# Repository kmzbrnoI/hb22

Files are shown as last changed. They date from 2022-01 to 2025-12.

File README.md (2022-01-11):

HB22
====

DCC signal booster

## Features

* Input voltage: track+1V – 35 V **DC**
* Output voltage: 14–25 V DCC
* Maximum output current: 3 A
* Adjustable output voltage
* Stepdown for stabilization (energy-effective)
* No big cooler needed
* Analog current limitation to 3 A
* DCC skew rate limitation
* RailCom support
* Possibility to connect expansion module for integration with railroad-control system
* Current sensing, voltage sensing, temperature sensing
* Short-circuit detection, (configurable) automatic restore after short-circuit

## Available expansion modules

- [MTBbus expansion module](exp-mtb)

## Principles

Main MCU does all safety-critical operations:

* Detection of short-circuit
* Railcom pause insertion

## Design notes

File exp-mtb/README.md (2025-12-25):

HB22 MTBbus expansion module
============================

The module allows communication with HB22 booster over
[MTBbus](https://mtb.kmz-brno.cz/).

## Module inputs

1. `BAI` Booster active [bool]
  - `BAO` && `BO` && `DCCI`
2. `BO` Booster ok [bool]
  - Communication with HB22 main MCU ok && HB22 main MCU reports status ok
3. `DCCI` Valid DCC on input [bool]
4. `SC` Shortcut [bool]

### Analog inputs

1. `OV` Output voltage
2. `OC` Output current
3. `TVR` Voltage regulator temperature
4. `TCR` Current limiter temperature

## Module outputs

1. `BAO` Booster active [bool]
2. `SCR` Shortcut renewal active [bool]

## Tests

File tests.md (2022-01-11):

Testovací scénáře zesilovače HB22
=================================

* Vysoké napětí na vstupu
* Nízké napětí na vstupu
* Opačné napětí na vstupu (standardní i vysoké)
* Standardní napětí přivedeno na výstup místo na vstup
* Standardní napětí přivedeno na vstup i na výstup
* Vysoké napětí přivedeno na výstup (vstup aktivní i neaktivní)
* Prohozené zapojení vstupu a výstupu
* Propojený vstup a výstup, přivedeno napětí
* Osazený, ale nenapájený expandér
* Spojení výstupů dvou HB22
  - Galvanicky spojené zesilovače
  - Galvanicky rozpojené zesilovače
* Spojení výstupů dvou HB22 překřížené
  - Galvanicky spojené zesilovače
  - Galvanicky rozpojené zesilovače
* Spojení výstupů HB22 a jiného zesilovače
  - Galvanicky spojené zesilovače
  - Galvanicky rozpojené zesilovače
* Spojení výstupů HB22 a jiného zesilovače překřížené
  - Galvanicky spojené zesilovače
  - Galvanicky rozpojené zesilovače
* Elektrostatický impuls na IO konektorech

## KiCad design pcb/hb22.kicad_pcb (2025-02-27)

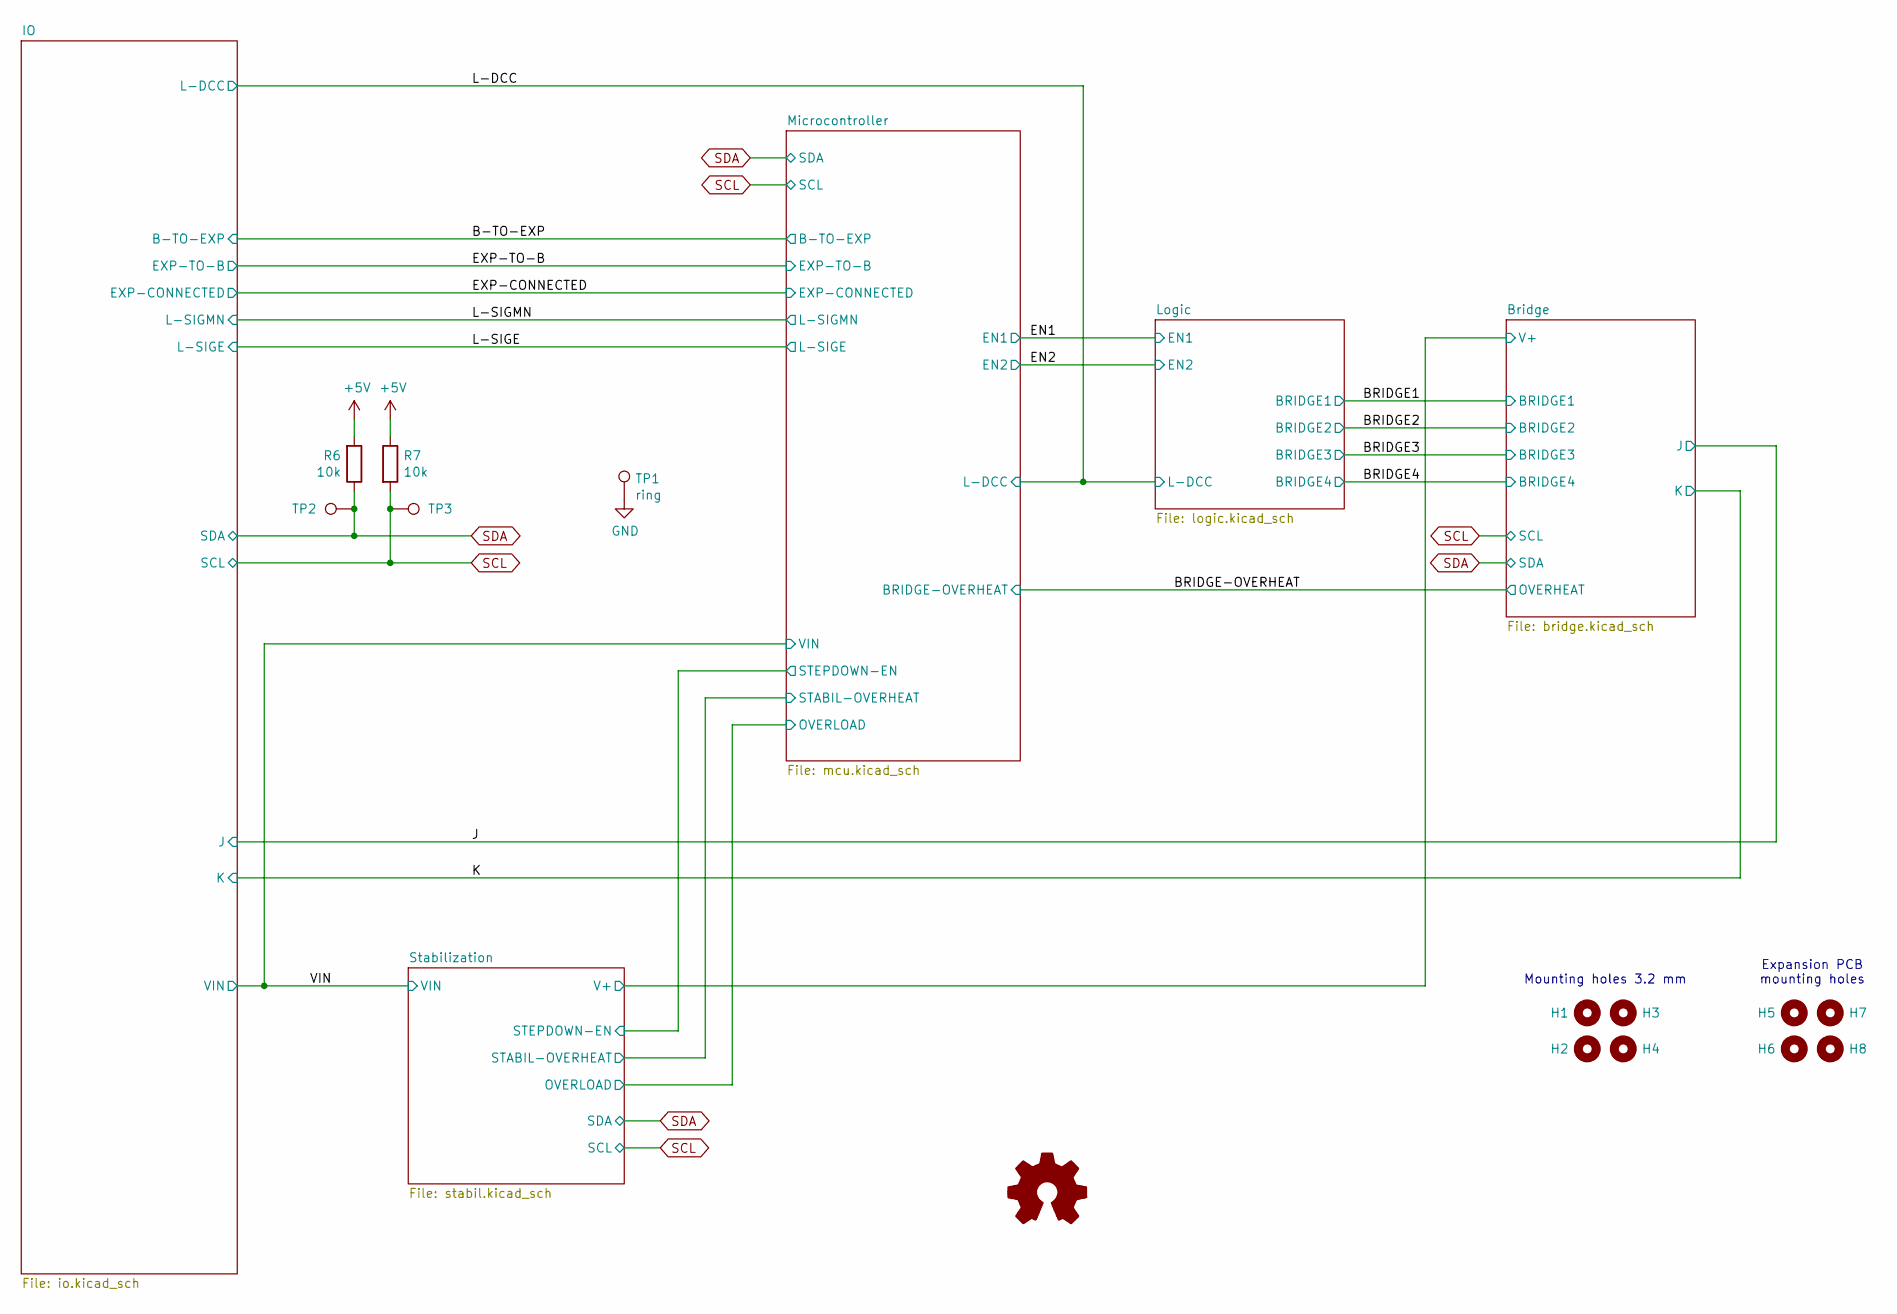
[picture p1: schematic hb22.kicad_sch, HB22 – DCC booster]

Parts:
H1, H2, H3, H4, H5, H6, H7, H8: MountingHole_3.2mm_M3_Pad
R6, R7: 10k; R_0805_2012Metric; LCSC C17414
TP1: ring; TestPoint_Loop_D1.80mm_Drill1.0mm_Beaded
TP2, TP3: TestPoint; TestPoint_Pad_D1.0mm

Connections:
+5V: R6.2, R7.1; also elsewhere on the board
GND: TP1.1; also elsewhere on the board
SCL: R7.2, TP3.1; also elsewhere on the board
SDA: R6.1, TP2.1; also elsewhere on the board

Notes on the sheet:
Mounting holes 3.2 mm
Expansion PCB mounting holes

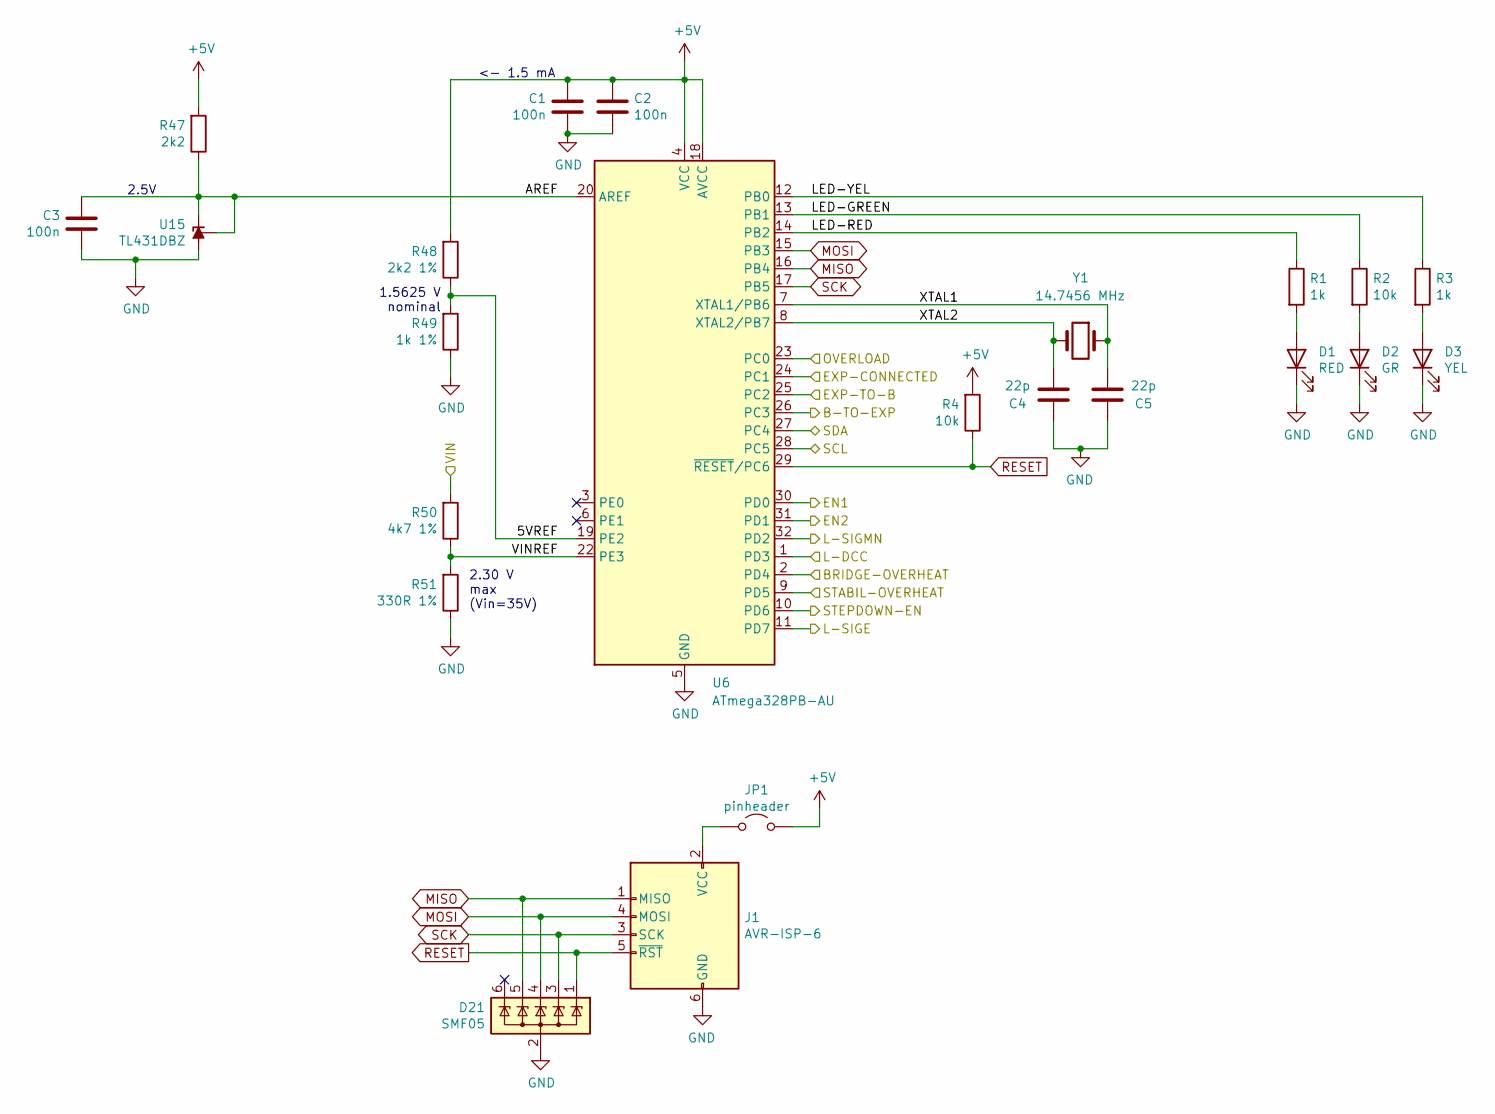
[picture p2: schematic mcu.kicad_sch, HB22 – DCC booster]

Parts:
C1, C2, C3: 100n; C_0805_2012Metric; LCSC C49678
C4, C5: 22p; C_0805_2012Metric; LCSC C1804
D1: RED; LED_0805_2012Metric; LCSC C84256
D2: GR; LED_0805_2012Metric; LCSC C2297
D3: YEL; LED_0805_2012Metric; LCSC C2293
D21: SMF05; SOT-363_SC-70-6
J1: AVR-ISP-6; PinHeader_2x03_P2.54mm_Vertical
JP1: pinheader; PinHeader_1x02_P2.54mm_Vertical
R1, R3: 1k; R_0805_2012Metric; LCSC C17513
R2: 10k; R_0805_2012Metric; LCSC C17513
R4: 10k; R_0805_2012Metric; LCSC C17414
R47: 2k2; R_0805_2012Metric
R48: 2k2 1%; R_0805_2012Metric
R49: 1k 1%; R_0805_2012Metric
R50: 4k7 1%; R_0805_2012Metric
R51: 330R 1%; R_0805_2012Metric
U6: ATmega328PB-AU; TQFP-32_7x7mm_P0.8mm
U15: TL431DBZ; SOT-23; LCSC C3113
Y1: 14.7456 MHz; Crystal_SMD_HC49-SD; LCSC C240976

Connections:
+5V: C1.2, C2.1, JP1.1 (A), R4.2, R47.2, R48.2, U6.4 (VCC), U6.18 (AVCC); also elsewhere on the board
/B-TO-EXP: U6.26 (PC3); also elsewhere on the board
/BRIDGE-OVERHEAT: U6.2 (PD4); also elsewhere on the board
/EN1: U6.30 (PD0); also elsewhere on the board
/EN2: U6.31 (PD1); also elsewhere on the board
/EXP-CONNECTED: U6.24 (PC1); also elsewhere on the board
/EXP-TO-B: U6.25 (PC2); also elsewhere on the board
/L-DCC: U6.1 (PD3); also elsewhere on the board
/L-SIGE: U6.11 (PD7); also elsewhere on the board
/L-SIGMN: U6.32 (PD2); also elsewhere on the board
/Microcontroller/5VREF: R48.1, R49.2, U6.19 (PE2)
/Microcontroller/AREF: C3.2, R47.1, U6.20 (AREF), U15.1 (K), U15.2 (REF)
/Microcontroller/LED-GREEN: R2.1, U6.13 (PB1)
/Microcontroller/LED-RED: R1.1, U6.14 (PB2)
/Microcontroller/LED-YEL: R3.1, U6.12 (PB0)
/Microcontroller/OVERLOAD: U6.23 (PC0); also elsewhere on the board
/Microcontroller/STABIL-OVERHEAT: U6.9 (PD5); also elsewhere on the board
/Microcontroller/STEPDOWN-EN: U6.10 (PD6); also elsewhere on the board
/Microcontroller/VINREF: R50.1, R51.2, U6.22 (PE3)
/Microcontroller/XTAL1: C5.1, U6.7 (XTAL1/PB6), Y1.1
/Microcontroller/XTAL2: C4.2, U6.8 (XTAL2/PB7), Y1.2
/VIN: R50.2; also elsewhere on the board
GND: C1.1, C2.2, C3.1, C4.1, C5.2, D1.1 (K), D2.1 (K), D3.1 (K), D21.2 (A), J1.6 (GND), R49.1, R51.1, U6.5 (GND), U6.21 (GND), U15.3 (A); also elsewhere on the board
MISO: D21.5 (K), J1.1 (MISO), U6.16 (PB4)
MOSI: D21.4 (K), J1.4 (MOSI), U6.15 (PB3)
unnamed: D1.2 (A), R1.2
unnamed: D2.2 (A), R2.2
unnamed: D3.2 (A), R3.2
unnamed: J1.2 (VCC), JP1.2 (B)
RESET: D21.1 (K), J1.5 (~RST), R4.1, U6.29 (~RESET/PC6)
SCK: D21.3 (K), J1.3 (SCK), U6.17 (PB5)
SCL: U6.28 (PC5); also elsewhere on the board
SDA: U6.27 (PC4); also elsewhere on the board

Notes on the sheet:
1.5625 V nominal
<- 1.5 mA
2.5V
2.30 V max (Vin=35V)

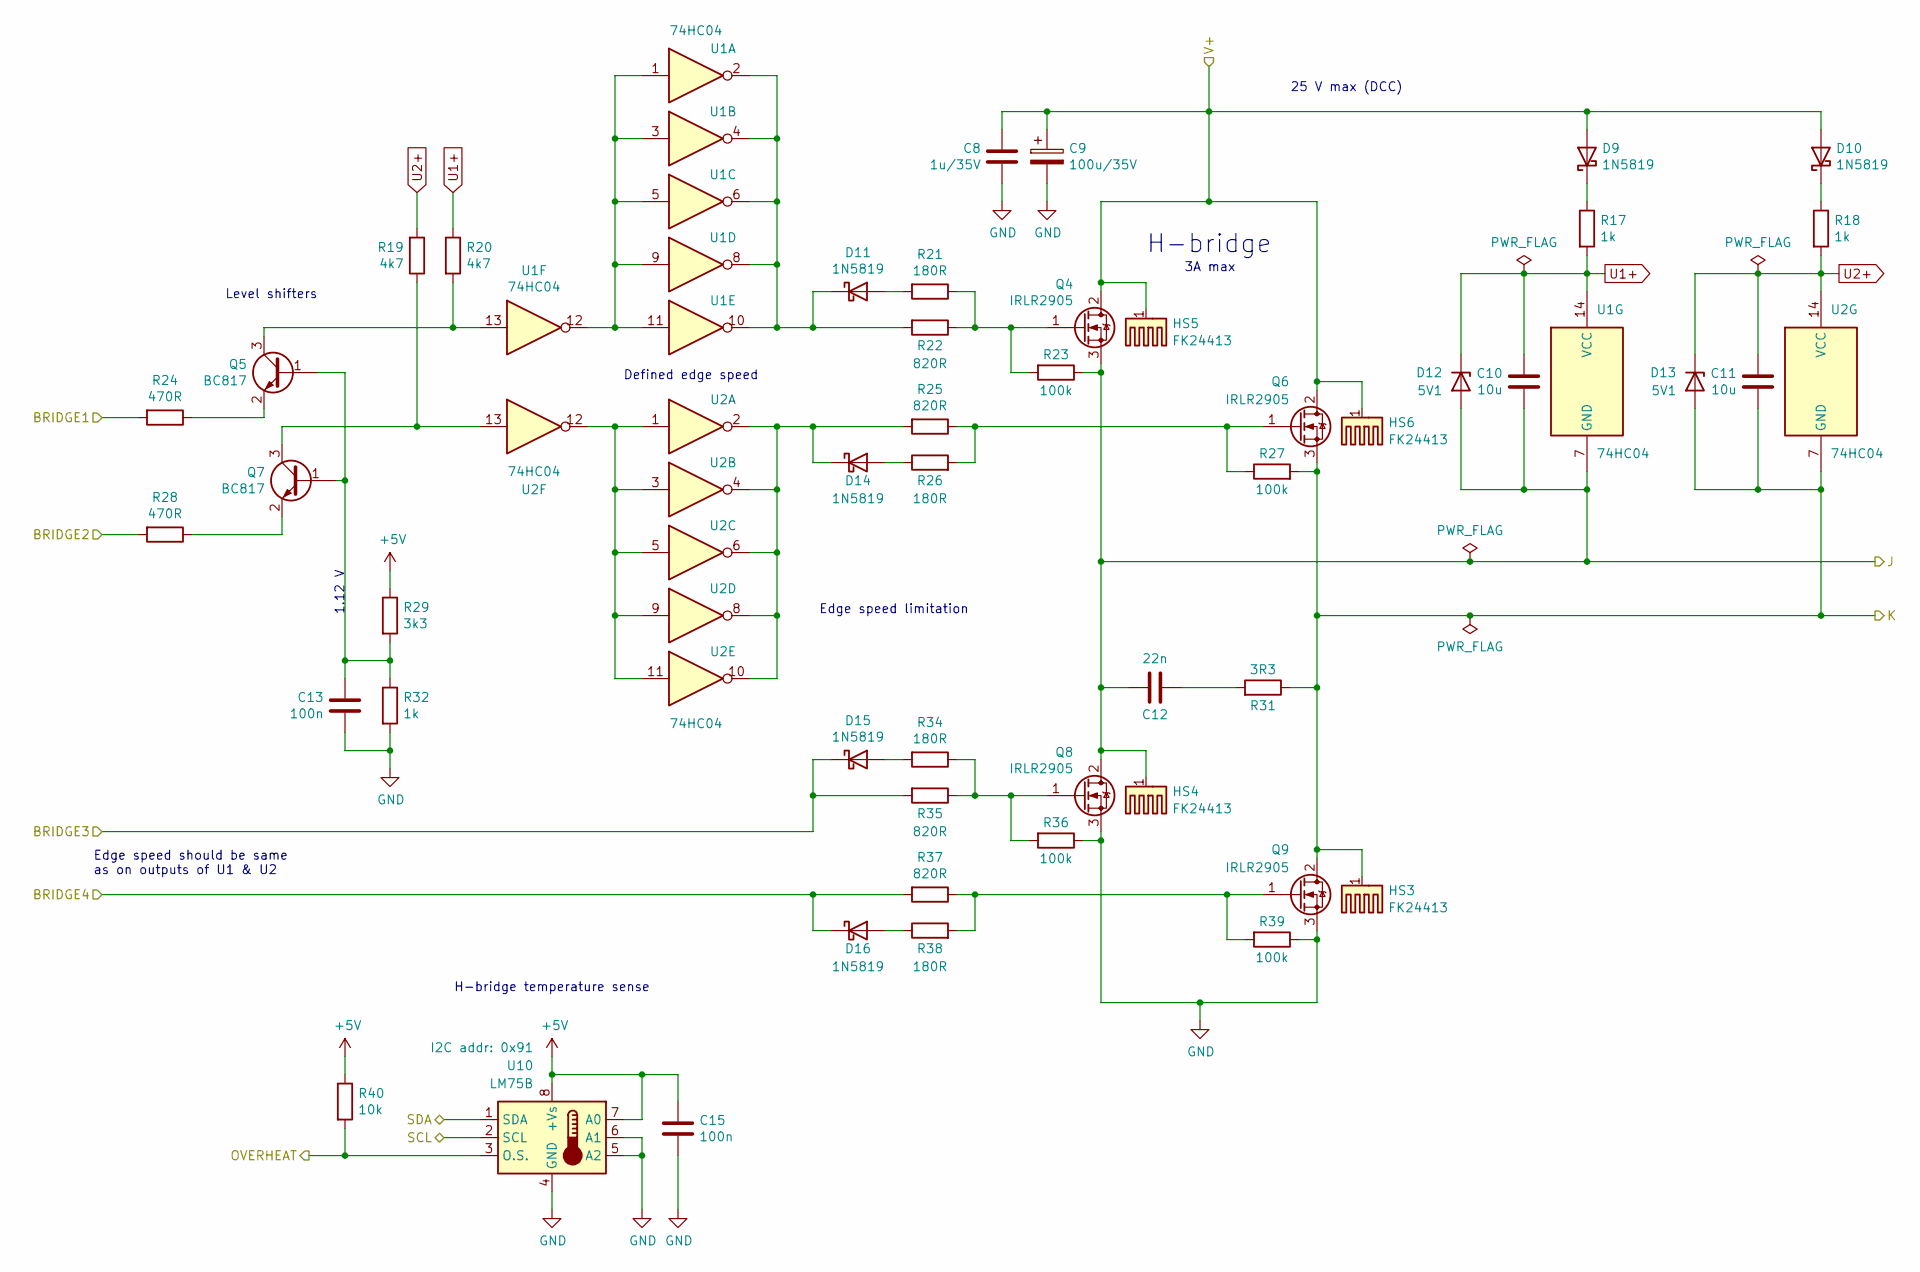
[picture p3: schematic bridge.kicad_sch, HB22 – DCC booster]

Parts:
C8: 1u/35V; C_0805_2012Metric
C9: 100u/35V; CP_Radial_D6.3mm_P2.50mm
C10, C11: 10u; C_0805_2012Metric
C12: 22n; C_0805_2012Metric
C13, C15: 100n; C_0805_2012Metric
D9, D10, D11, D14, D15, D16: 1N5819; D_SOD-123
D12, D13: 5V1; SOT-23
HS3, HS4, HS5, HS6: FK24413; Heatsink_Fischer_FK24413DPAK_23x13mm
Q4, Q6, Q8, Q9: IRLR2905; TO-252-2
Q5, Q7: BC817; SOT-23
R17, R18: 1k; R_2512_6332Metric
R19, R20: 4k7; R_0805_2012Metric
R21, R26, R34, R38: 180R; R_0805_2012Metric
R22, R25, R35, R37: 820R; R_0805_2012Metric
R23, R27, R36, R39: 100k; R_0805_2012Metric
R24, R28: 470R; R_0805_2012Metric
R29: 3k3; R_0805_2012Metric
R31: 3R3; R_0805_2012Metric
R32: 1k; R_0805_2012Metric
R40: 10k; R_0805_2012Metric
U1, U2: 74HC04; DIP-14_W8.89mm_SMDSocket_LongPads
U10: LM75B; SOIC-8_3.9x4.9mm_P1.27mm

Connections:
+5V: C15.1, R29.1, R40.1, U10.7 (A0), U10.8 (+Vs); also elsewhere on the board
/BRIDGE1: R24.2; also elsewhere on the board
/BRIDGE2: R28.2; also elsewhere on the board
/BRIDGE3: D15.1 (K), R35.2; also elsewhere on the board
/BRIDGE4: D16.1 (K), R37.2; also elsewhere on the board
/BRIDGE-OVERHEAT: R40.2, U10.3 (O.S.); also elsewhere on the board
/Bridge/V+: C8.2, C9.1, D9.2 (A), D10.2 (A), HS5.1, HS6.1, Q4.2 (D), Q6.2 (D); also elsewhere on the board
/J: C10.1, C12.2, D12.1 (A), HS4.1, Q4.3 (S), Q8.2 (D), R23.1, U1.7 (GND); also elsewhere on the board
/K: C11.1, D13.1 (A), HS3.1, Q6.3 (S), Q9.2 (D), R27.2, R31.1, U2.7 (GND); also elsewhere on the board
GND: C8.1, C9.2, C13.1, C15.2, Q8.3 (S), Q9.3 (S), R32.2, R36.1, R39.1, U10.4 (GND), U10.5 (A2), U10.6 (A1); also elsewhere on the board
unnamed: C12.1, R31.2
unnamed: D9.1 (K), R17.1
unnamed: D10.1 (K), R18.1
unnamed: D11.2 (A), R21.2
unnamed: D11.1 (K), R22.2, U1.2, U1.4, U1.6, U1.8, U1.10
unnamed: D14.2 (A), R26.1
unnamed: D14.1 (K), R25.2, U2.2, U2.4, U2.6, U2.8, U2.10
unnamed: D15.2 (A), R34.2
unnamed: D16.2 (A), R38.1
unnamed: Q4.1 (G), R21.1, R22.1, R23.2
unnamed: C13.2, Q5.1 (B), Q7.1 (B), R29.2, R32.1
unnamed: Q5.3 (C), R20.2, U1.13
unnamed: Q5.2 (E), R24.1
unnamed: Q6.1 (G), R25.1, R26.2, R27.1
unnamed: Q7.3 (C), R19.1, U2.13
unnamed: Q7.2 (E), R28.1
unnamed: Q8.1 (G), R34.1, R35.1, R36.2
unnamed: Q9.1 (G), R37.1, R38.2, R39.2
unnamed: U1.1, U1.3, U1.5, U1.9, U1.11, U1.12
unnamed: U2.1, U2.3, U2.5, U2.9, U2.11, U2.12
SCL: U10.2 (SCL); also elsewhere on the board
SDA: U10.1 (SDA); also elsewhere on the board
U1+: C10.2, D12.3 (K), R17.2, R20.1, U1.14 (VCC)
U2+: C11.2, D13.3 (K), R18.2, R19.2, U2.14 (VCC)

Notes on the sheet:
25 V max (DCC)
3A max
1.12 V
H-bridge
Defined edge speed
Edge speed should be same as on outputs of U1 & U2
Edge speed limitation
H-bridge temperature sense
Level shifters

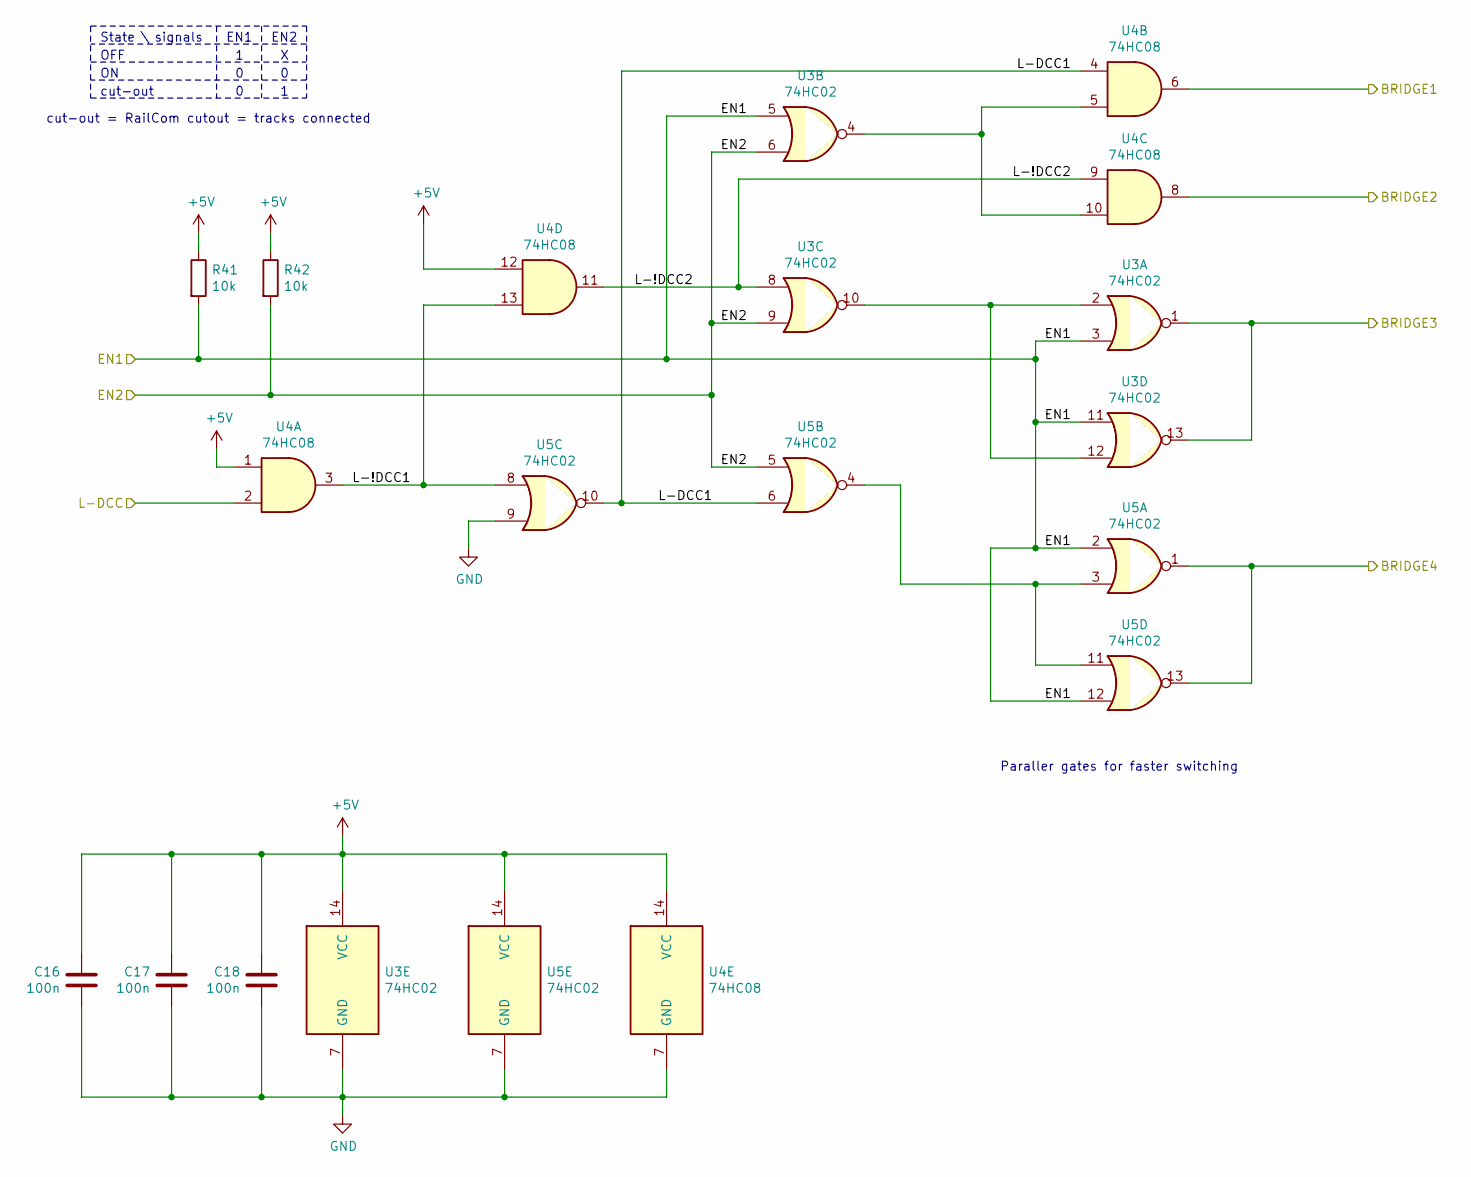
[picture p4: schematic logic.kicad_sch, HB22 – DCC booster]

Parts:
C16, C17, C18: 100n; C_0805_2012Metric
R41, R42: 10k; R_0805_2012Metric
U3, U5: 74HC02; DIP-14_W8.89mm_SMDSocket_LongPads
U4: 74HC08; DIP-14_W8.89mm_SMDSocket_LongPads

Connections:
+5V: C16.2, C17.2, C18.2, R41.1, R42.1, U3.14 (VCC), U4.1, U4.12, U4.14 (VCC), U5.14 (VCC); also elsewhere on the board
/BRIDGE1: U4.6; also elsewhere on the board
/BRIDGE2: U4.8; also elsewhere on the board
/BRIDGE3: U3.1, U3.13; also elsewhere on the board
/BRIDGE4: U5.1, U5.13; also elsewhere on the board
/EN1: R41.2, U3.3, U3.5, U3.11, U5.2, U5.12; also elsewhere on the board
/EN2: R42.2, U3.6, U3.9, U5.5; also elsewhere on the board
/L-DCC: U4.2; also elsewhere on the board
/Logic/L-!DCC1: U4.3, U4.13, U5.8
/Logic/L-!DCC2: U3.8, U4.9, U4.11
/Logic/L-DCC1: U4.4, U5.6, U5.10
GND: C16.1, C17.1, C18.1, U3.7 (GND), U4.7 (GND), U5.7 (GND), U5.9; also elsewhere on the board
unnamed: U3.4, U4.5, U4.10
unnamed: U3.2, U3.10, U3.12
unnamed: U5.3, U5.4, U5.11

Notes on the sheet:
EN2
State \ signals
OFF
Paraller gates for faster switching
cut-out = RailCom cutout = tracks connected
cut-out
EN1

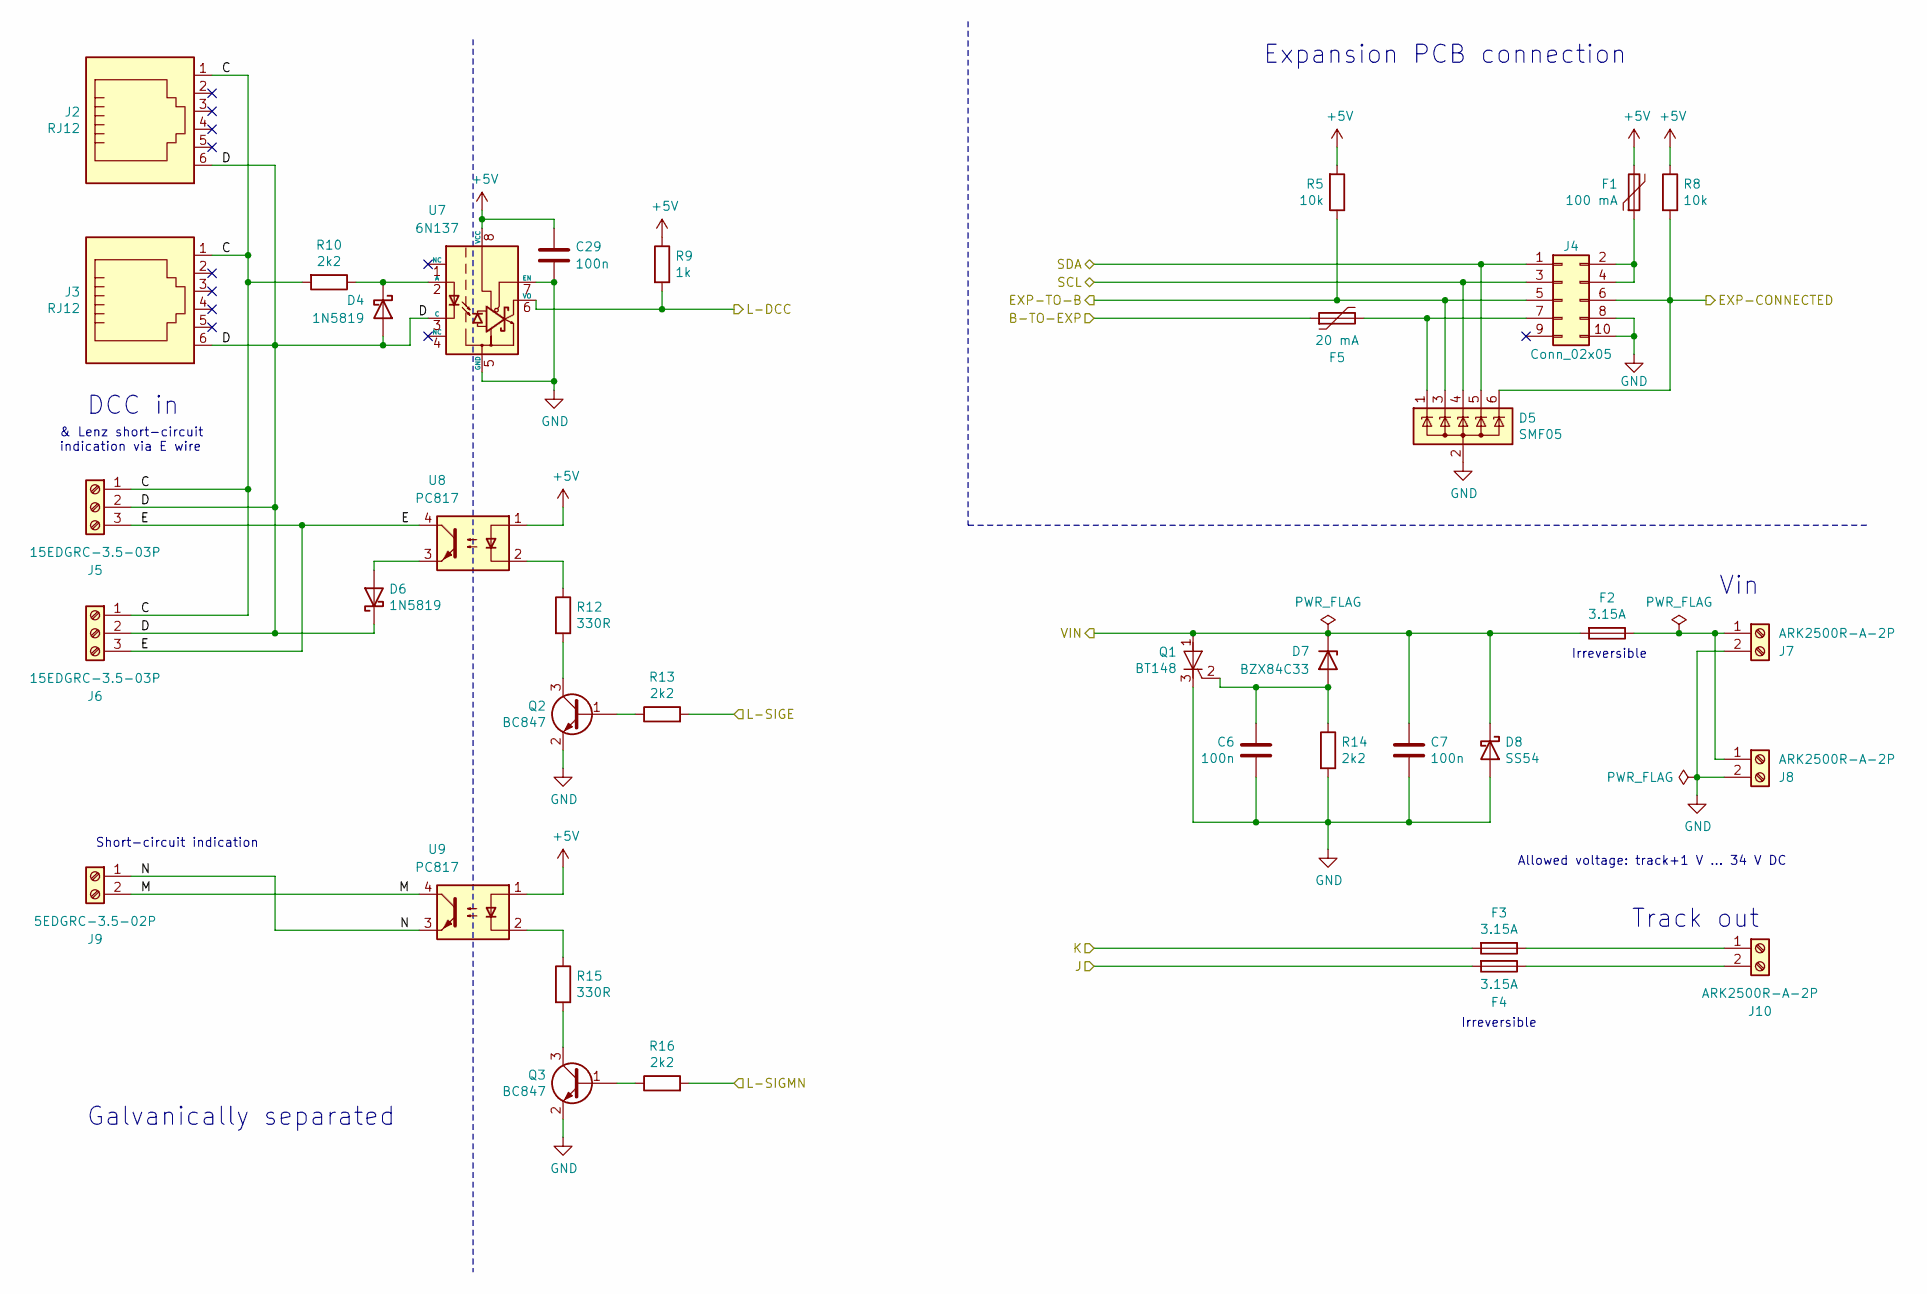
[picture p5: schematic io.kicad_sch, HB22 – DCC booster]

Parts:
C6, C7, C29: 100n; C_0805_2012Metric
D4, D6: 1N5819; D_SOD-123
D5: SMF05; SOT-363_SC-70-6
D7: BZX84C33; SOT-23
D8: SS54; D_SMA
F1: 100 mA; Fuse_1206_3216Metric
F2, F3, F4: 3.15A; Fuseholder_Cylinder-5x20mm_Stelvio-Kontek_PTF78_Horizontal_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
F5: 20 mA; Fuse_1206_3216Metric
J2, J3: RJ12; RJ25_Wayconn_MJEA-660X1_Horizontal
J4: Conn_02x05; PinSocket_2x05_P2.54mm_Vertical
J5, J6: 15EDGRC-3.5-03P; PhoenixContact_MC_1,5_3-G-3.5_1x03_P3.50mm_Horizontal
J7, J8, J10: ARK2500R-A-2P; PhoenixContact_MSTBA_2,5_2-G_1x02_P5.00mm_Horizontal
J9: 5EDGRC-3.5-02P; PhoenixContact_MC_1,5_2-G-3.5_1x02_P3.50mm_Horizontal
Q1: BT148; SOT-223
Q2, Q3: BC847; SOT-23
R5: 10k; R_0805_2012Metric; LCSC C17414
R8: 10k; R_0805_2012Metric
R9: 1k; R_0805_2012Metric
R10, R13, R14, R16: 2k2; R_0805_2012Metric
R12, R15: 330R; R_0805_2012Metric
U7: 6N137; DIP-8_W8.89mm_SMDSocket_LongPads
U8, U9: PC817; DIP-4_W8.89mm_SMDSocket_LongPads

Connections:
+5V: C29.1, F1.2, R5.2, R8.1, R9.1, U7.8 (VCC), U8.1, U9.1; also elsewhere on the board
/B-TO-EXP: F5.1; also elsewhere on the board
/EXP-CONNECTED: D5.6 (K), J4.6, R8.2; also elsewhere on the board
/EXP-TO-B: D5.3 (K), J4.5, R5.1; also elsewhere on the board
/IO/C: J2.1, J3.1, J5.1, J6.1, R10.2
/IO/D: D4.2 (A), D6.1 (K), J2.6, J3.6, J5.2, J6.2, U7.3 (C)
/IO/E: J5.3, J6.3, U8.4
/IO/M: J9.2, U9.4
/IO/N: J9.1, U9.3
/J: F4.2; also elsewhere on the board
/K: F3.2; also elsewhere on the board
/L-DCC: R9.2, U7.6 (VO); also elsewhere on the board
/L-SIGE: R13.2; also elsewhere on the board
/L-SIGMN: R16.2; also elsewhere on the board
/VIN: C7.1, D7.3 (K), D8.1 (K), F2.2, Q1.1 (A); also elsewhere on the board
GND: C6.1, C7.2, C29.2, D5.2 (A), D8.2 (A), J4.8, J4.10, J7.2, J8.2, Q1.3 (K), Q2.2 (E), Q3.2 (E), R14.2, U7.5 (GND), U7.7 (EN); also elsewhere on the board
unnamed: D4.1 (K), R10.1, U7.2 (A)
unnamed: D6.2 (A), U8.3
unnamed: C6.2, D7.1 (A), Q1.2 (G), R14.1
unnamed: F1.1, J4.2, J4.4
unnamed: D5.1 (K), F5.2, J4.7
unnamed: F2.1, J7.1, J8.1
unnamed: F3.1, J10.1
unnamed: F4.1, J10.2
unnamed: Q2.1 (B), R13.1
unnamed: Q2.3 (C), R12.2
unnamed: Q3.1 (B), R16.1
unnamed: Q3.3 (C), R15.2
unnamed: R12.1, U8.2
unnamed: R15.1, U9.2
SCL: D5.4 (K), J4.3; also elsewhere on the board
SDA: D5.5 (K), J4.1; also elsewhere on the board

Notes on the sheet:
Allowed voltage: track+1 V ... 34 V DC
Irreversible
Vin
& Lenz short-circuit indication via E wire
Galvanically separated
Track out
Expansion PCB connection
Short-circuit indication
DCC in

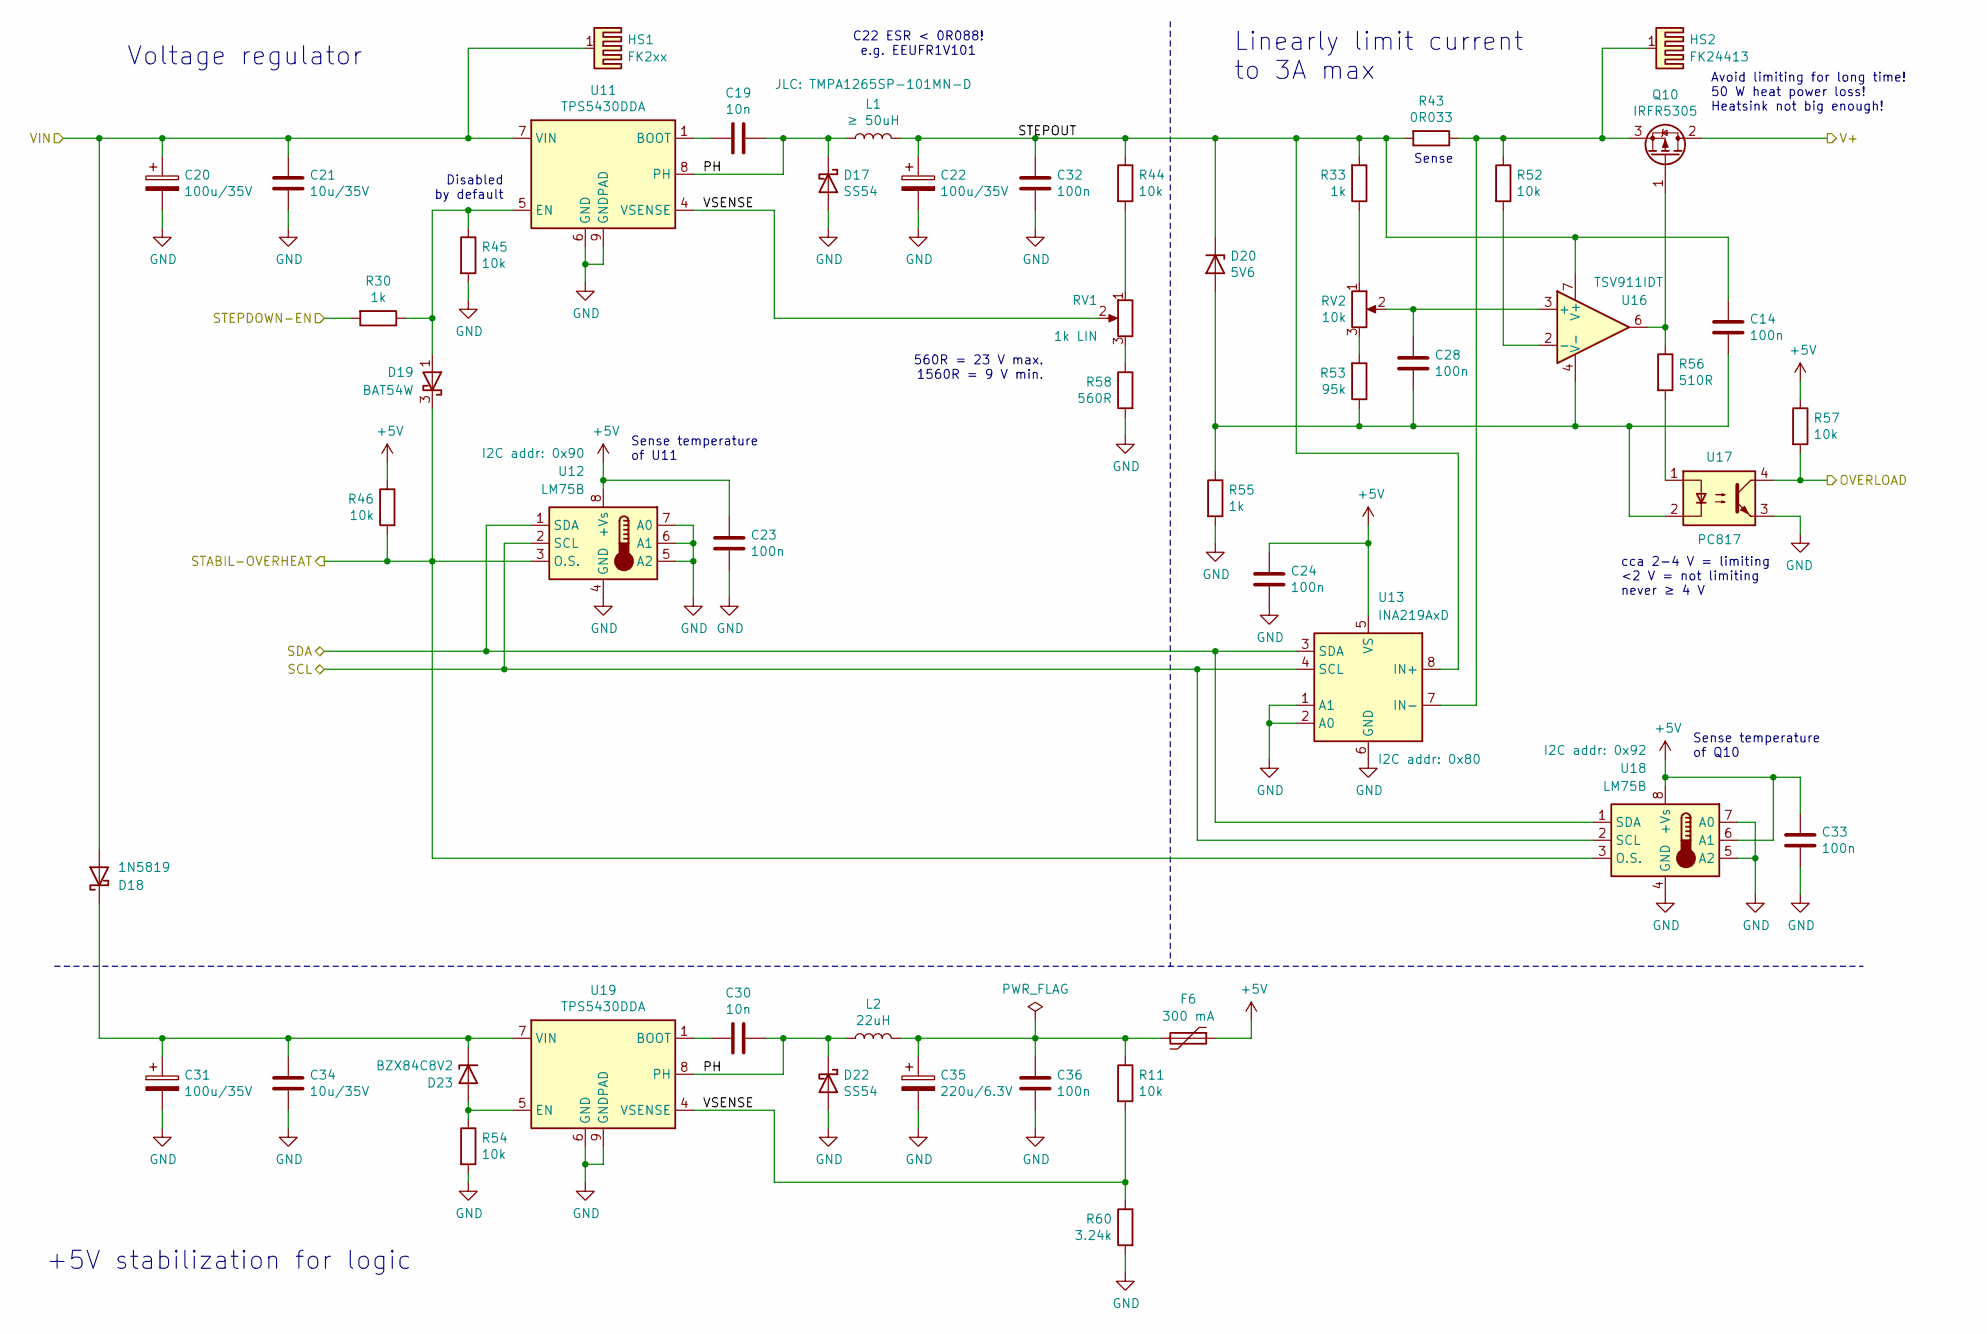
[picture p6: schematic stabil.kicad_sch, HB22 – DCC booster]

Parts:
C14, C23, C24, C28, C32, C33, C36: 100n; C_0805_2012Metric
C19, C30: 10n; C_0805_2012Metric
C20, C31: 100u/35V; CP_Radial_D6.3mm_P2.50mm
C21, C34: 10u/35V; C_0805_2012Metric
C22: 100u/35V; CP_Radial_D8.0mm_P3.50mm
C35: 220u/6.3V; CP_Radial_D8.0mm_P3.50mm
D17, D22: SS54; D_SMA
D18: 1N5819; D_SOD-123
D19: BAT54W; SOT-323_SC-70
D20: 5V6; SOT-23
D23: BZX84C8V2; SOT-23
F6: 300 mA; Fuse_2920_7451Metric
HS1: FK2xx; Heatsink_Fischer_FK24413DPAK_23x13mm
HS2: FK24413; Heatsink_Fischer_FK24413DPAK_23x13mm
L1: ≥ 50uH; L_TaiTech_TMPC1265_13.5x12.5mm; JLC TMPA1265SP-101MN-D
L2: 22uH; L_Changjiang_FNR4020S
Q10: IRFR5305; TO-252-2
R11, R44, R45, R46, R52, R54, R57: 10k; R_0805_2012Metric
R30, R33: 1k; R_0805_2012Metric
R43: 0R033; R_2512_6332Metric
R53: 95k; R_0805_2012Metric
R55: 1k; R_2512_6332Metric
R56: 510R; R_0805_2012Metric
R58: 560R; R_0805_2012Metric
R60: 3.24k; R_0805_2012Metric
RV1: 1k LIN; Potentiometer_Piher_PT-6-V_Vertical
RV2: 10k; Potentiometer_Piher_PT-6-V_Vertical
U11, U19: TPS5430DDA; TI_SO-PowerPAD-8_ThermalVias
U12, U18: LM75B; SOIC-8_3.9x4.9mm_P1.27mm
U13: INA219AxD; SOIC-8_3.9x4.9mm_P1.27mm
U16: TSV911IDT; SOIC-8_3.9x4.9mm_P1.27mm
U17: PC817; DIP-4_W8.89mm_SMDSocket_LongPads

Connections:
+5V: C23.1, C24.1, C33.1, F6.1, R46.1, R57.1, U12.8 (+Vs), U13.5 (VS), U18.6 (A1), U18.8 (+Vs); also elsewhere on the board
/Bridge/V+: Q10.2 (D); also elsewhere on the board
/Microcontroller/OVERLOAD: R57.2, U17.4; also elsewhere on the board
/Microcontroller/STABIL-OVERHEAT: D19.3 (K), R46.2, U12.3 (O.S.), U18.3 (O.S.); also elsewhere on the board
/Microcontroller/STEPDOWN-EN: R30.2; also elsewhere on the board
/Stabilization/PH: C19.1, C30.1, D17.1 (K), D22.1 (K), L1.1, L2.1, U11.8 (PH), U19.8 (PH)
/Stabilization/STEPOUT: C14.1, C22.1, C32.1, D20.3 (K), L1.2, R33.2, R43.2, R44.1, U13.8 (IN+), U16.7 (V+)
/Stabilization/VSENSE: R11.2, R60.1, RV1.2, U11.4 (VSENSE), U19.4 (VSENSE)
/VIN: C20.1, C21.1, D18.2 (A), HS1.1, U11.7 (VIN); also elsewhere on the board
GND: C20.2, C21.2, C22.2, C23.2, C24.2, C31.2, C32.2, C33.2, C34.2, C35.2, C36.2, D17.2 (A), D22.2 (A), R45.2, R54.2, R55.2, R58.2, R60.2, U11.6 (GND), U11.9 (GNDPAD), U12.4 (GND), U12.5 (A2), U12.6 (A1), U12.7 (A0), U13.1 (A1), U13.2 (A0), U13.6 (GND), U17.3, U18.4 (GND), U18.5 (A2), U18.7 (A0), U19.6 (GND), U19.9 (GNDPAD); also elsewhere on the board
unnamed: C35.1, C36.1, F6.2, L2.2, R11.1
unnamed: C31.1, C34.1, D18.1 (K), D23.3 (K), U19.7 (VIN)
unnamed: D19.1 (A), R30.1, R45.1, U11.5 (EN)
unnamed: C14.2, C28.2, D20.1 (A), R53.1, R55.1, U16.4 (V-), U17.2
unnamed: D23.1 (A), R54.1, U19.5 (EN)
unnamed: Q10.1 (G), R56.1, U16.6
unnamed: HS2.1, Q10.3 (S), R43.1, R52.1, U13.7 (IN-)
unnamed: R33.1, RV2.1
unnamed: R44.2, RV1.1
unnamed: R53.2, RV2.3
unnamed: R56.2, U17.1
unnamed: R58.1, RV1.3
unnamed: C19.2, U11.1 (BOOT)
unnamed: C28.1, RV2.2, U16.3 (+)
unnamed: R52.2, U16.2 (-)
unnamed: C30.2, U19.1 (BOOT)
SCL: U12.2 (SCL), U13.4 (SCL), U18.2 (SCL); also elsewhere on the board
SDA: U12.1 (SDA), U13.3 (SDA), U18.1 (SDA); also elsewhere on the board

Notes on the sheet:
Avoid limiting for long time! 50 W heat power loss! Heatsink not big enough!
560R = 23 V max. 1560R = 9 V min.
C22 ESR < 0R088! e.g. EEUFR1V101
Sense temperature of U11
Voltage regulator
cca 2-4 V = limiting <2 V = not limiting never ≥ 4 V
Disabled by default
+5V stabilization for logic
Sense
Sense temperature of Q10
Linearly limit current to 3A max

Board: 4 copper layers, 182 parts (0 on the bottom side), 106 nets, no tracks yet.

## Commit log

2021-12-28 Add empty KiCad project.
    [hb22.kicad_pcb, hb22.sch]
2021-12-28 Add MTB expansion PCB schematics.
    [exp-mtb.kicad_pcb, exp-mtb.sch]
2021-12-28 Add descripton etc.
    [hb22.sch]
2021-12-28 MTB EXP: add GPIOs between booster & expander.
    [exp-mtb.sch]
2021-12-28 MTB EXP: annotate schematics, ERC clean.
    [exp-mtb.sch]
2021-12-28 Add LCSC numbers.
    [exp-mtb.sch]
2021-12-28 MTB exp: add testpads.
    [exp-mtb.sch]
2021-12-28 Add mountingholes.
    [exp-mtb.sch]
2021-12-29 Add MCU ATmega, add expansion connector.
    [hb22.sch, io.sch, mcu.sch]
2021-12-31 Add H bridge.
    [bridge.sch, hb22.sch, io.sch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]
2022-01-01 Add logic schematics.
    [bridge.sch, hb22.sch, io.sch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]
2022-01-01 Add IO schematics.
    [io.sch]
2022-01-01 Vin & Vout: add protections.
    [io.sch]
2022-01-01 Add stabilization schematics (5V + stepdown).
    [bridge.sch, hb22.sch, io.sch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]
2022-01-01 Add INA219 & LM75B.
    [hb22.sch, stabil.sch]
2022-01-01 EXP-MTB: add 6N137 pull-ups.
    [exp-mtb.sch]
2022-01-01 onnect hierarchical schematics in root schematic.
    [bridge.sch, hb22.sch, io.sch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]
2022-01-03 Add Vin & 5 V measurements.
    [hb22.sch, mcu.sch, stabil.sch]
2022-01-03 Bridge: use single voltage reference.
    [bridge.sch]
2022-01-08 Move i2c pullups to main schematics.
    [bridge.sch, hb22.sch, io.sch]
2022-01-08 First round of footprint annotations.
    [bridge.sch, hb22.sch, io.sch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]
2022-01-09 Connect temperature sensor to stepdown enable.
    Add hardware overcurrent protection (independent on MCU).
    [stabil.sch]
2022-01-09 Bridge: change transistors (too high Rds).
    [bridge.sch, io.sch, stabil.sch]
2022-01-09 Add first version of linear limiter.
    [stabil.sch]
2022-01-09 Add overload indication to MCU.
    [stabil.sch]
2022-01-10 EXP-MTB: add MCU "active" pin.
    [exp-mtb.sch]
2022-01-10 EXP-MTB: ad missing 100n capacitor to 75176.
    [exp-mtb.sch]
2022-01-10 EXP-MTB: add protection resistor.
    [exp-mtb.sch]
2022-01-10 Stepdown: hardware limit output voltage to 9V-25 V.
    [stabil.sch]
2022-01-11 Add programming connector TVS protection.
    [mcu.sch, stabil.sch]
2022-01-11 Change divider to set maximum stepdown voltage to 23 V.
    [stabil.sch]
2022-01-21 Migrate to KiCad 6.
    [bridge.kicad_sch, bridge.sch, hb22.kicad_pcb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]
2025-02-20 Update to KiCad 8.
    [bridge.kicad_sch, hb22.kicad_sch, io.kicad_sch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]
2025-02-20 Remove misplaced wires.
    [hb22.kicad_sch]
2025-02-20 Tweak exapander connector.
    [io.kicad_sch]
2025-02-20 Use 1N5819 instead of 1N4148.
    [bridge.kicad_sch, io.kicad_sch, mcu.kicad_sch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]
2025-02-20 gitignore: add *.lck.
    [bridge.kicad_sch]
2025-02-20 Export root page escription to other pages.
    [bridge.kicad_sch, hb22.kicad_sch, io.kicad_sch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]
2025-02-21 Add capacitor to U7, fix new parts.
    [io.kicad_sch, stabil.kicad_sch]
2025-02-21 Use normal SMD footprints, avoid handsolder.
    [bridge.kicad_sch, hb22.kicad_sch, io.kicad_sch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]
2025-02-21 Add stabil heatsinks, minor improvements.
    [bridge.kicad_sch, hb22.kicad_sch, io.kicad_sch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]
2025-02-21 Add temp. sensor for current limiter.
    [bridge.kicad_sch, stabil.kicad_sch]
2025-02-21 Add heasinks to output bridge.
    [bridge.kicad_sch]
2025-02-22 Specify screw terminals, add footprints.
    [hb22.kicad_pcb, hb22.kicad_sch, io.kicad_sch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]
2025-02-22 Migrate exp-mtb to KiCad 8.
    [exp-mtb.kicad_sch, exp-mtb.sch]
2025-02-22 exp-mtb: move pcb to 'pcb' directory.
    [exp-mtb.kicad_pcb, exp-mtb.kicad_sch]
2025-02-22 exp-mtb: remove address jumpers.
    Address will be set in EEPROM.
    [exp-mtb.kicad_sch]
2025-02-22 Use polyfuse instead of resistor for main-exp protection.
    Make voltage measurement possible.
    [exp-mtb.kicad_sch, io.kicad_sch, mcu.kicad_sch]
2025-02-22 exp-mtb: use 78M05 instead of 78L05.
    75176 can draw quite high current.
    [exp-mtb.kicad_sch]
2025-02-22 exp-mtb: use standard SMD packages, no handsolder.
    [exp-mtb.kicad_sch, hb22.kicad_sch]
2025-02-23 Bridge: use IRLR2905 transistors instead of IRFR4105.
    IRFR4105 seem not to be available.
    [bridge.kicad_sch, hb22.kicad_pcb]
2025-02-23 Add F5 missing footprint.
    [bridge.kicad_sch, hb22.kicad_pcb, io.kicad_sch]
2025-02-26 Use switched power supply for 5V internal.
    78M05 would have 2.5 W of heat loss on it @ 30V input.
    Other minor improvements.
    [bridge.kicad_sch, io.kicad_sch, stabil.kicad_sch]
2025-02-26 Change pages order.
    [hb22.kicad_sch, stabil.kicad_sch]
2025-02-27 Use ATmega328pb instead of ATmega328p.
    Reason: obtain some free pins as a reserve.
    [hb22.kicad_pcb, hb22.kicad_sch, io.kicad_sch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]

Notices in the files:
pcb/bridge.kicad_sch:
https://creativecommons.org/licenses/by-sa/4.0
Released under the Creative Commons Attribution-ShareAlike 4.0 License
